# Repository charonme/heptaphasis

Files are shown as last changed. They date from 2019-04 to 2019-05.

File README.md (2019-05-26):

# [heptaphasis](http://charon.sk/heptaphasis)
### 7-phase quadrature sine LFO for eurorack
based on [Yusynth Quadrature VC-LFO](http://yusynth.net/Modular/EN/QUAD-LFO/index.html)

[Muffwiggler thread](https://www.muffwiggler.com/forum/viewtopic.php?t=215780)

<dl>
<dt>Frequency range</dt><dd>19 Hz - 0.0008 Hz (20 min)</dd>
<dt>Output phases</dt><dd>0&deg;, 45&deg;, 90&deg;, 135&deg;, 180&deg;, 225&deg;, 270&deg;</dd>
<dt>Amplitude</dt><dd>+-5V (10Vpp)</dd>
<dt>Power draw</dt><dd>+30mA, -27mA (depends on used LEDs)</dd>
<dt>Startup stabilisation</dt><dd>7 sec</dd>
<dt>PCB size</dt><dd>100x45.2mm</dd>
</dl>

[BOM](http://charon.sk/heptaphasis/#bom) / [Mouser project](https://www.mouser.com/ProjectManager/ProjectDetail.aspx?AccessID=b96a90f5ef)

breadboard test (https://www.youtube.com/watch?v=A-SHyvcifvg "breadboard test")
breadboard test (https://www.youtube.com/watch?v=bgxGyFDmLBA "crossfading 7 sources")

---
kopimi

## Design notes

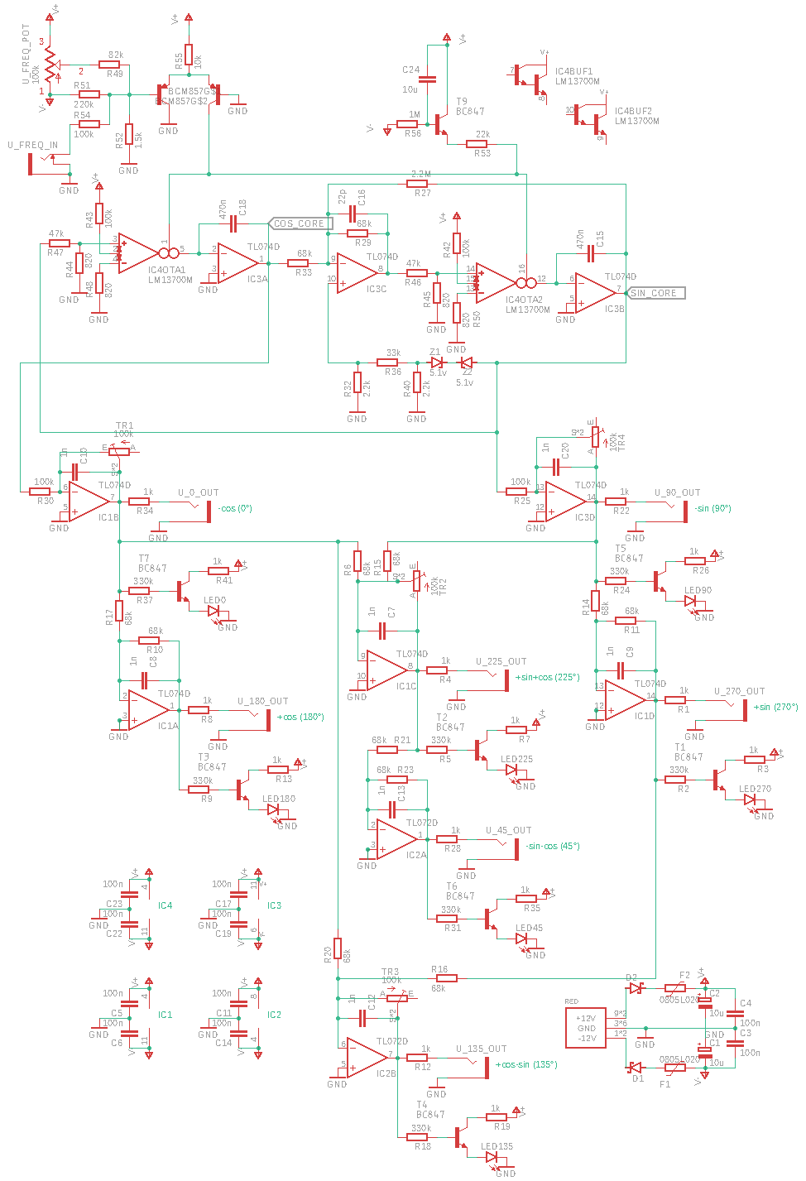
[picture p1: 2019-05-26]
heptaphasis_schematic.png

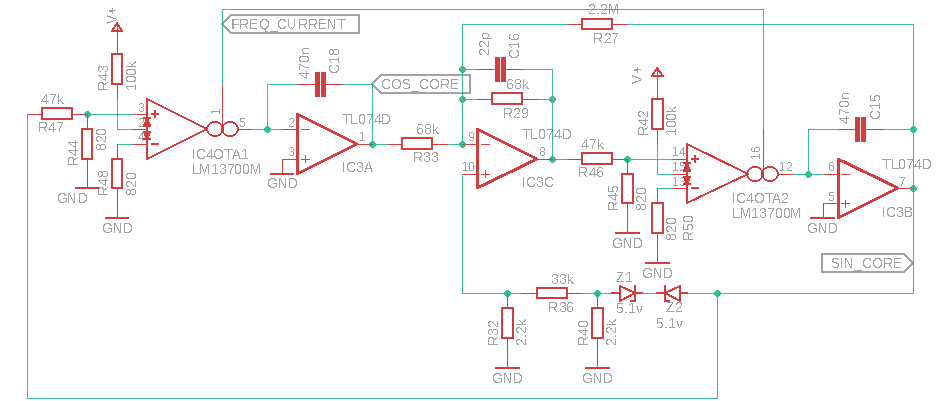
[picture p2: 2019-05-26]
circuit_core.png

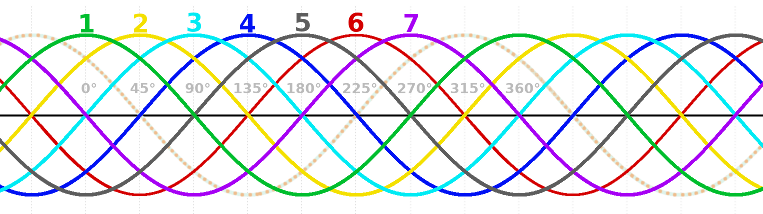
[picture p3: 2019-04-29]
heptaphasis_waves.png

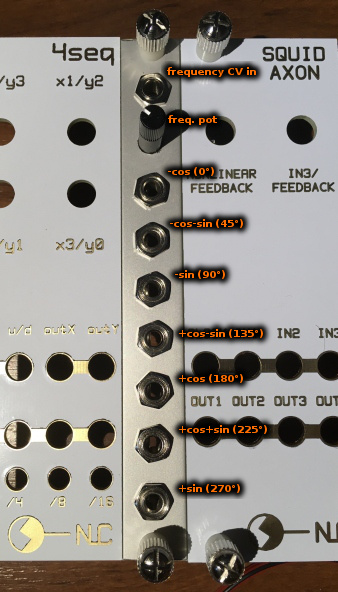
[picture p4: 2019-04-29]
heptaphasis_panel.jpg

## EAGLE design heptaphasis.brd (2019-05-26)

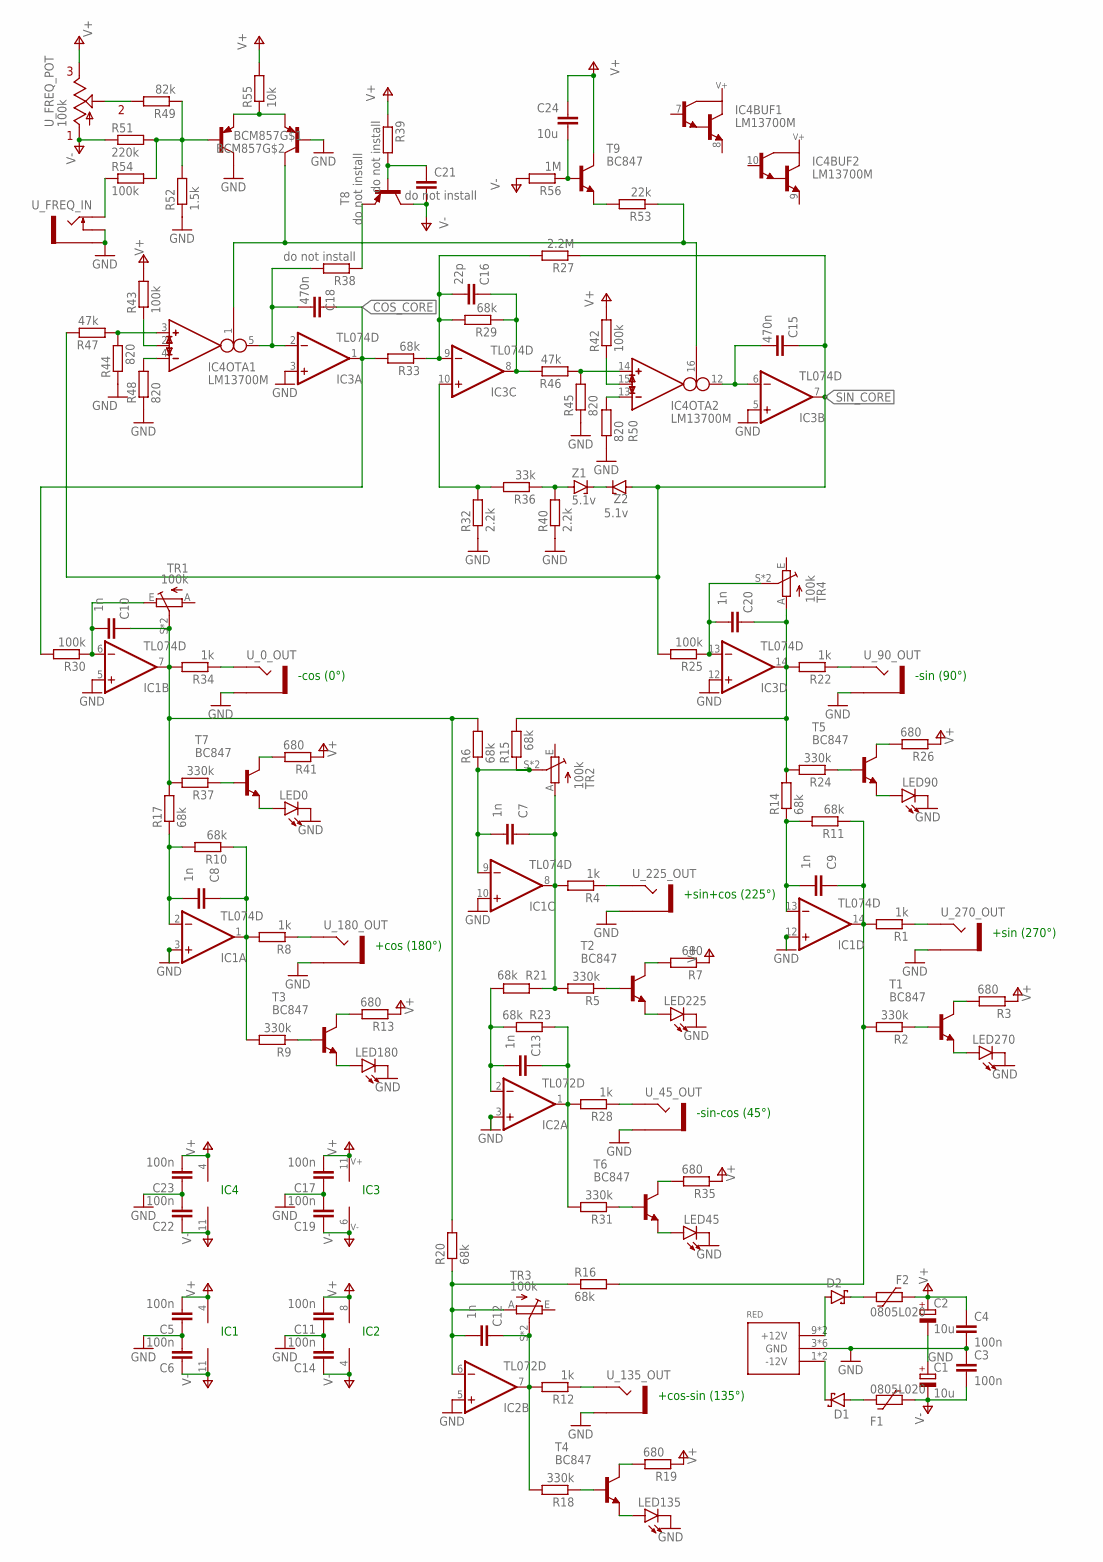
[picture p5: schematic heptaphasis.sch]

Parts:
BCM857: BCM857DS; SOT457R_PHILIPS
C1, C2: 10u; E2-5
C3, C4, C5, C6, C11, C14, C17, C19, C22, C23: 100n; C0805
C7, C8, C9, C10, C12, C13, C20: 1n; C0805
C15, C18: 470n; C0805
C16: 22p; C0805
C21: do not install; C0805
C24: 10u; C0805
D1, D2: VERTICAL_SCHOTTKY; DO41-7
F1, F2: 0805L020; 0805L
IC1, IC3: TL074D; SO14
IC2: TL072D; SO08
IC4: LM13700M; SO16
LED0, LED45, LED90, LED135, LED180, LED225, LED270: LED3MM
R1, R4, R8, R12, R22, R28, R34: 1k; R0805
R2, R5, R9, R18, R24, R31, R37: 330k; R0805
R3, R7, R13, R19, R26, R35, R41: 680; R0805
R6, R10, R11, R14, R15, R16, R17, R20, R21, R23, R29, R33: 68k; R0805
R25, R30, R42, R43, R54: 100k; R0805
R27: 2.2M; R0805
R32, R40: 2.2k; R0805
R36: 33k; R0805
R38, R39: do not install; R0805
R44, R45, R48, R50: 820; R0805
R46, R47: 47k; R0805
R49: 82k; R0805
R51: 220k; R0805
R52: 1.5k; R0805
R53: 22k; R0805
R55: 10k; R0805
R56: 1M; R0805
RED: POWER_SIMPLE10; POWER_10
T1, T2, T3, T4, T5, T6, T7, T9: BC847; SOT23
T8: do not install; SOT23
TR1, TR2, TR3, TR4: 100k; S64YW
U_0_OUT, U_45_OUT, U_90_OUT, U_135_OUT, U_180_OUT, U_225_OUT, U_270_OUT: PJ302M_NO_NORM
U_FREQ_IN: PJ302M
U_FREQ_POT: 100k; RK097-SINGLE-ELEMENT
Z1, Z2: 5.1v; SOD80C

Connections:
0OUT: R34.1, U_0_OUT.TIP
45OUT: R28.1, U_45_OUT.TIP
90OUT: R22.1, U_90_OUT.TIP
135OUT: R12.1, U_135_OUT.TIP
180OUT: R8.1, U_180_OUT.TIP
225OUT: R4.1, U_225_OUT.TIP
270OUT: R1.1, U_270_OUT.TIP
+12DIODE_FUSE: D2.C, F2.2
+12SUPPLY: D2.A, RED.9 (+12V), RED.10 (+12V)
-12DIODE_FUSE: D1.A, F1.2
-12SUPPLY: D1.C, RED.1 (-12V), RED.2 (-12V)
BUF0OUT: C10.1, IC1.7 (OUT), R6.2, R17.2, R20.2, R34.2, R37.2, TR1.S, TR1.S@1 (S)
BUF0_IN: C10.2, IC1.6 (-IN), R30.1, TR1.E
BUF45OUT: C13.1, IC2.1 (OUT), R23.1, R28.2, R31.2
BUF45_IN: C13.2, IC2.2 (-IN), R21.1, R23.2
BUF90OUT: C20.1, IC3.14 (OUT), R14.2, R15.2, R22.2, R24.2, TR4.A
BUF90_IN: C20.2, IC3.13 (-IN), R25.1, TR4.S, TR4.S@1 (S)
BUF135OUT: C12.1, IC2.7 (OUT), R12.2, R18.2, TR3.S, TR3.S@1 (S)
BUF135_IN: C12.2, IC2.6 (-IN), R16.1, R20.1, TR3.A
BUF180OUT: C8.1, IC1.1 (OUT), R8.2, R9.2, R10.1
BUF180_IN: C8.2, IC1.2 (-IN), R10.2, R17.1
BUF225OUT: C7.1, IC1.8 (OUT), R4.2, R5.2, R21.2, TR2.A
BUF225_IN: C7.2, IC1.9 (-IN), R6.1, R15.1, TR2.S, TR2.S@1 (S)
BUF270OUT: C9.1, IC1.14 (OUT), R1.2, R2.2, R11.1, R16.2
BUF270_IN: C9.2, IC1.13 (-IN), R11.2, R14.1
COS_CORE: C18.1, IC3.1 (OUT), R30.2, R33.2
COS_INTEG_IN: C18.2, IC3.2 (-IN), IC4.5 (OUT), R38.2
COS_OTA1_IN+: IC4.3 (IN_P), R44.2, R47.1
COS_OTA1_NEGATIVE: IC4.4 (IN_N), R48.2
EXP_EMITTERS: BCM857.1 (E), BCM857.4 (E), R55.1
FREQ_CURRENT: BCM857.3 (C), IC4.1 (I_BIAS), IC4.16 (I_BIAS), R53.1
FREQ_CV_IN: R54.1, U_FREQ_IN.TIP
FREQ_EXP_IN: BCM857.2 (B), R49.1, R51.2, R52.2, R54.2
FREQ_POT: R49.2, U_FREQ_POT.P$5 (S)
GND: BCM857.5 (B), BCM857.6 (C), C1.+, C2.-, C3.1, C4.2, C5.1, C6.2, C11.1, C14.2, C17.1, C19.2, C22.2, C23.1, IC1.3 (+IN), IC1.5 (+IN), IC1.10 (+IN), IC1.12 (+IN), IC2.3 (+IN), IC2.5 (+IN), IC3.3 (+IN), IC3.5 (+IN), IC3.12 (+IN), LED0.K (C), LED45.K (C), LED90.K (C), LED135.K (C), LED180.K (C), LED225.K (C), LED270.K (C), R32.1, R40.1, R44.1, R45.1, R48.1, R50.1, R52.1, RED.3 (GND), RED.4 (GND), RED.5 (GND), RED.6 (GND), RED.7 (GND), RED.8 (GND), U_0_OUT.GND (SLEEVE), U_45_OUT.GND (SLEEVE), U_90_OUT.GND (SLEEVE), U_135_OUT.GND (SLEEVE), U_180_OUT.GND (SLEEVE), U_225_OUT.GND (SLEEVE), U_270_OUT.GND (SLEEVE), U_FREQ_IN.GND (SLEEVE), U_FREQ_IN.SW (SWITCH)
HP_SUM: C16.1, IC3.8 (OUT), R29.1, R46.2
LED0+: LED0.A, T7.2 (E)
LED0PWR: R41.2, T7.3 (C)
LED0SIG: R37.1, T7.1 (B)
LED45+: LED45.A, T6.2 (E)
LED45PWR: R35.2, T6.3 (C)
LED45SIG: R31.1, T6.1 (B)
LED90+: LED90.A, T5.2 (E)
LED90PWR: R26.2, T5.3 (C)
LED90SIG: R24.1, T5.1 (B)
LED135+: LED135.A, T4.2 (E)
LED135PWR: R19.2, T4.3 (C)
LED135SIG: R18.1, T4.1 (B)
LED180+: LED180.A, T3.2 (E)
LED180PWR: R13.2, T3.3 (C)
LED180SIG: R9.1, T3.1 (B)
LED225+: LED225.A, T2.2 (E)
LED225PWR: R7.2, T2.3 (C)
LED225SIG: R5.1, T2.1 (B)
LED270+: LED270.A, T1.2 (E)
LED270PWR: R3.2, T1.3 (C)
LED270SIG: R2.1, T1.1 (B)
LINEARIZING1: IC4.2 (I_DIODE), R43.1
LINEARIZING2: IC4.15 (I_DIODE), R42.1
NEG_FDBK: C16.2, IC3.9 (-IN), R27.2, R29.2, R33.1
SIN_CORE: C15.1, IC3.7 (OUT), R25.2, R27.1, R47.2, Z2.A
SIN_FEEDBACK: IC3.10 (+IN), R32.2, R36.2
SIN_INTEG_IN: C15.2, IC3.6 (-IN), IC4.12 (OUT)
SIN_OTA2_IN+: IC4.14 (IN_P), R45.2, R46.1
SIN_OTA2_NEGATIVE: IC4.13 (IN_N), R50.2
START_AMP_EMIT: R38.1, T8.2 (E)
START_AMP_GATE: C21.1, R39.2, T8.1 (B)
START_FREQ_EMIT: R53.2, T9.2 (E)
START_FREQ_GATE: C24.2, R56.1, T9.1 (B)
V+: C2.+, C4.1, C5.2, C11.2, C17.2, C23.2, C24.1, F2.1, IC1.4 (V+), IC2.8 (V+), IC3.4 (V+), IC4.11 (V+), R3.1, R7.1, R13.1, R19.1, R26.1, R35.1, R39.1, R41.1, R42.2, R43.2, R55.2, T9.3 (C), U_FREQ_POT.P$4 (E)
V-: C1.-, C3.2, C6.1, C14.1, C19.1, C21.2, C22.1, F1.1, IC1.11 (V-), IC2.4 (V-), IC3.11 (V-), IC4.6 (V-), R51.1, R56.2, T8.3 (C), U_FREQ_POT.P$6 (A)
ZENERS_CATHODES: Z1.C, Z2.C
ZENER_ANODE: R36.1, R40.2, Z1.A

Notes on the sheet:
-cos (0°)
+cos (180°)
+sin (270°)
-sin (90°)
-sin-cos (45°)
+sin+cos (225°)
+cos-sin (135°)
IC1
IC3
IC4
IC2

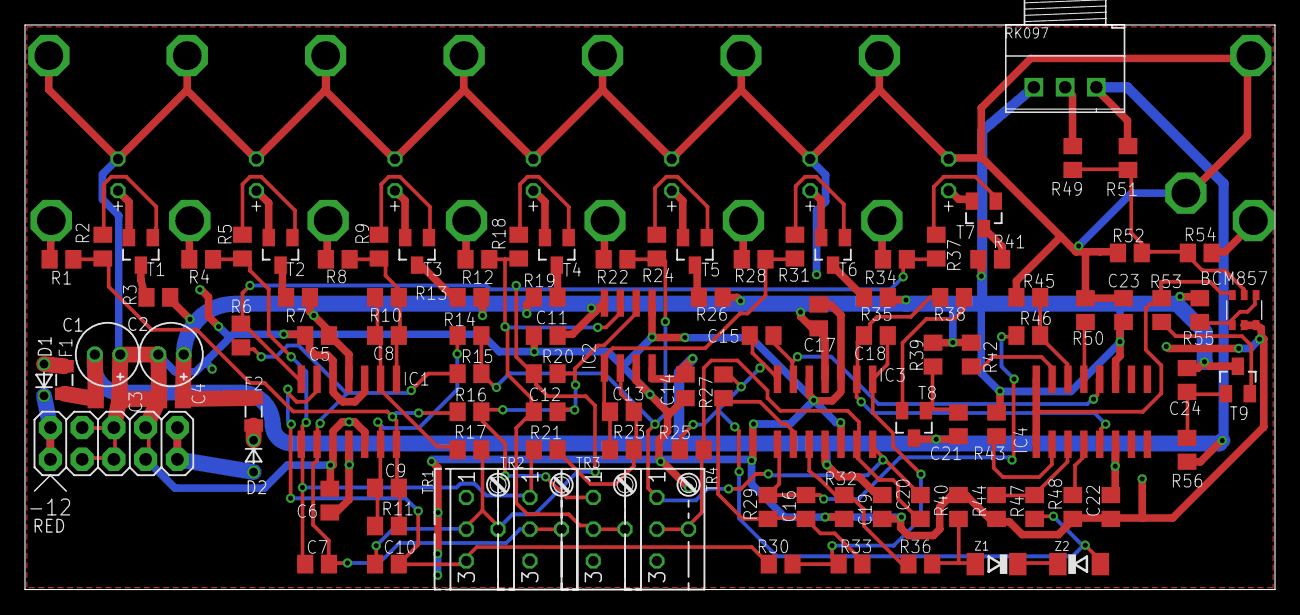
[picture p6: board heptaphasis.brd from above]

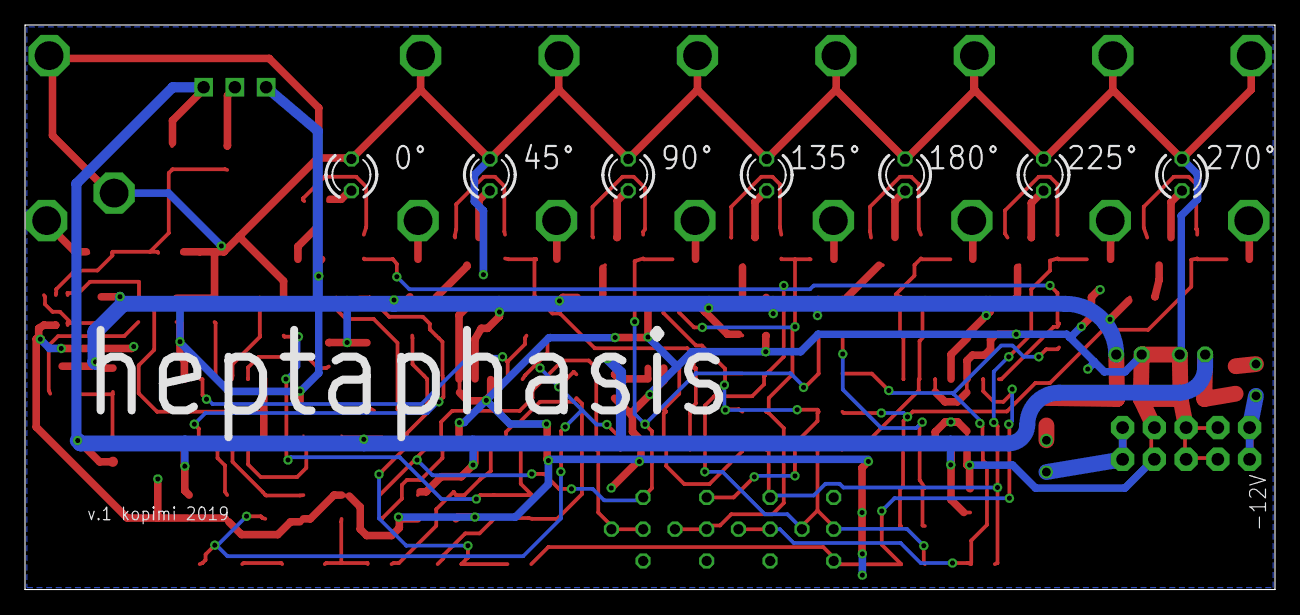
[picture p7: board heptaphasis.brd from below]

Board: 2 copper layers, 100.0 x 45.2 mm, 121 parts (7 on the bottom side), 73 nets.
